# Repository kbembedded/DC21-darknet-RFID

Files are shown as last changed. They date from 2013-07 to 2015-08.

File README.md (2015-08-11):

DC21-darknet-RFID
=================

Note: This project is deprecated in favor of the EM4100_Cloner available here: https://github.com/kbembedded/EM4100_Cloner

Send any quesions to kris@kbembedded.com

Software, schematics, board, etc. for the DEF CON21 darknet ARG in the HHV

This project is based on the RFID_Emulator from http://www.kukata86.com/en/description-and-development-RFID-emulator

The RFID-emulator/ folder contains sources for the pic12f683 microcontroller to act as two types of LF RFID cards.  A standard EM4100, as well as EM4450/EM4150 to be compatible with the RFID reader and RFID reader/writer module from Parallax.  

The RFID-readerwriter/ folder contains spin sources for a Parallax reader/writer module connected to a Propeller, using a 4x4 matrix keypad interface, and an HD44780 LCD screen.

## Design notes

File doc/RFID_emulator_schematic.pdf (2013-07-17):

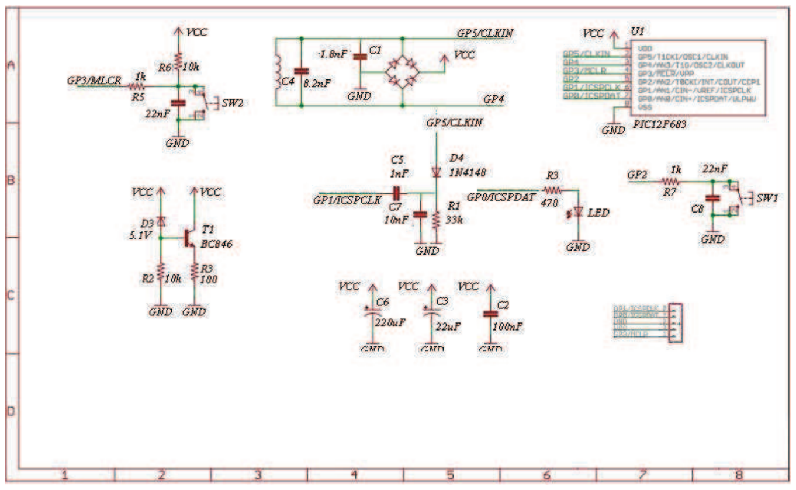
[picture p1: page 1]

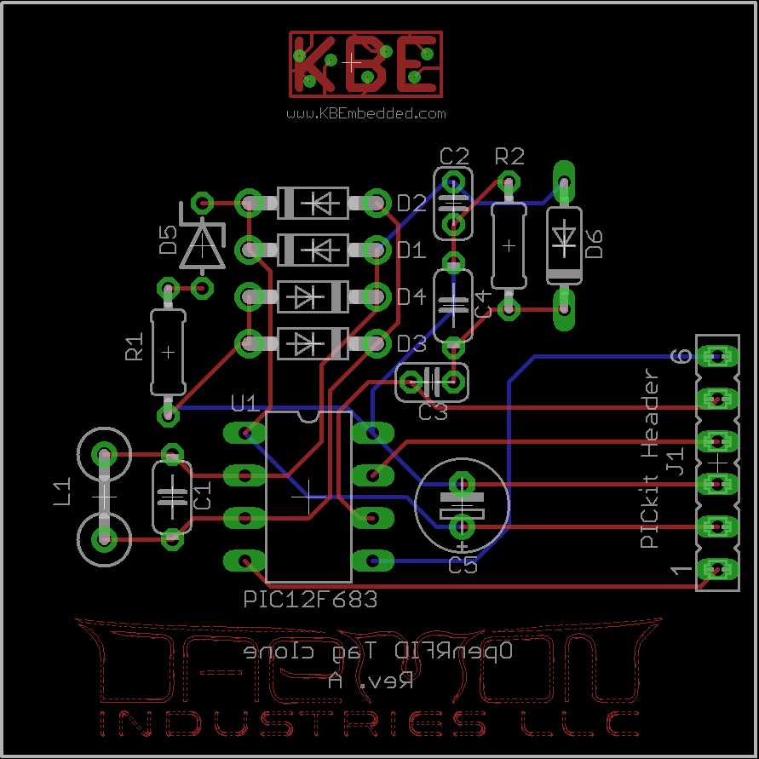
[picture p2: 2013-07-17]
eagle/openrfid.png

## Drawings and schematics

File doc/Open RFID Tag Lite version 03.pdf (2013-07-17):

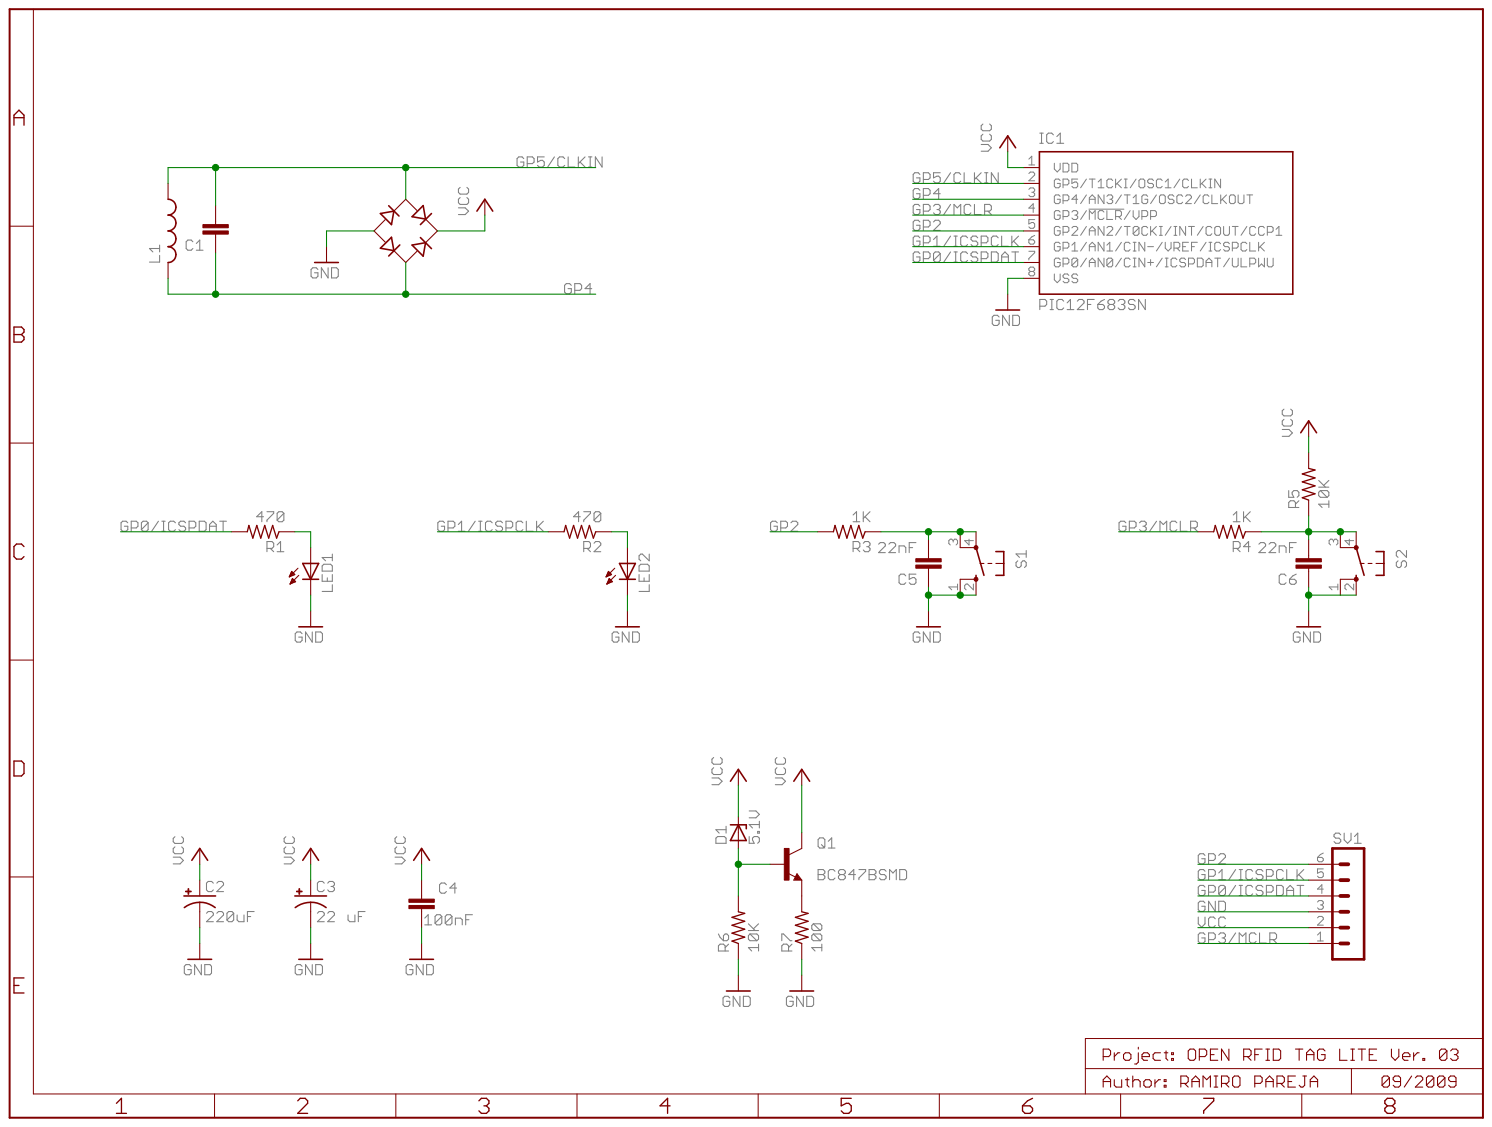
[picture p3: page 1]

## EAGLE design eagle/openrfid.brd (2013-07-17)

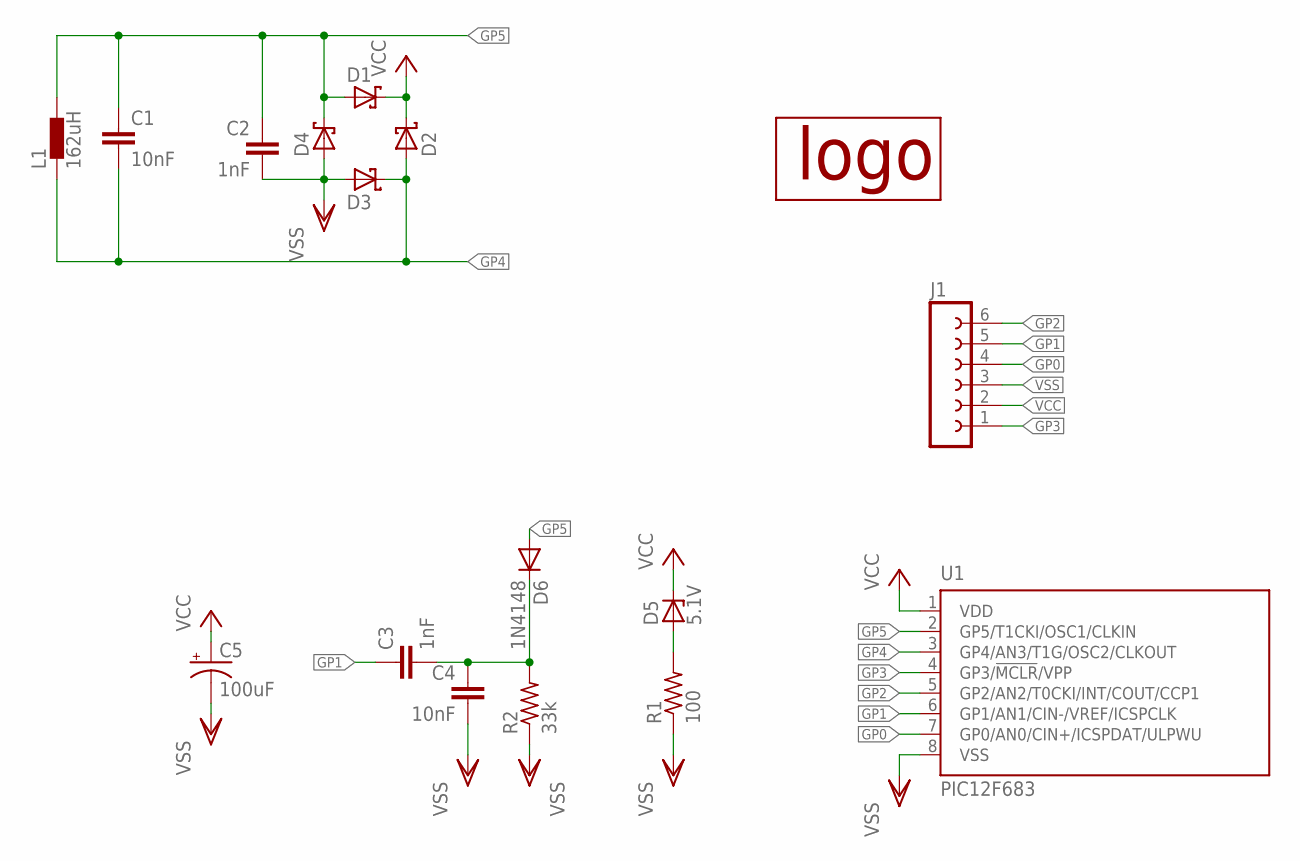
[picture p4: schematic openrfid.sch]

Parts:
C1, C4: 10nF; C050-024X044
C2, C3: 1nF; C025-024X044
C5: 100uF; E2,5-6E
D1, D2, D3, D4: 1N5817-B; DO41-7.6
D5: 5.1V; ZDIO-5
D6: 1N4148; DO35-7
J1: FE06-1; FE06
L1: 162uH; BL02RN2
R1: 100; 0204/7
R2: 33k; 0204/7
U1: PIC12F683; DIL8
U$1: KBELOGO-SILK

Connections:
GP0: J1.4, U1.7 (GP0/AN0/CIN+/ICSPDAT/ULPWU)
GP1: C3.1, J1.5, U1.6 (GP1/AN1/CIN-/VREF/ICSPCLK)
GP2: J1.6, U1.5 (GP2/AN2/T0CKI/INT/COUT/CCP1)
GP3: J1.1, U1.4 (GP3/!MCLR!/VPP)
GP4: C1.2, D2.A, D3.C, L1.1, U1.3 (GP4/AN3/T1G/OSC2/CLKOUT)
GP5: C1.1, C2.1, D1.A, D4.C, D6.A, L1.2, U1.2 (GP5/T1CKI/OSC1/CLKIN)
unnamed: D5.A, R1.2
unnamed: C3.2, C4.1, D6.C, R2.2
VCC: C5.+, D1.C, D2.C, D5.C, J1.2, U1.1 (VDD)
VSS: C2.2, C4.2, C5.-, D3.A, D4.A, J1.3, R1.1, R2.1, U1.8 (VSS)

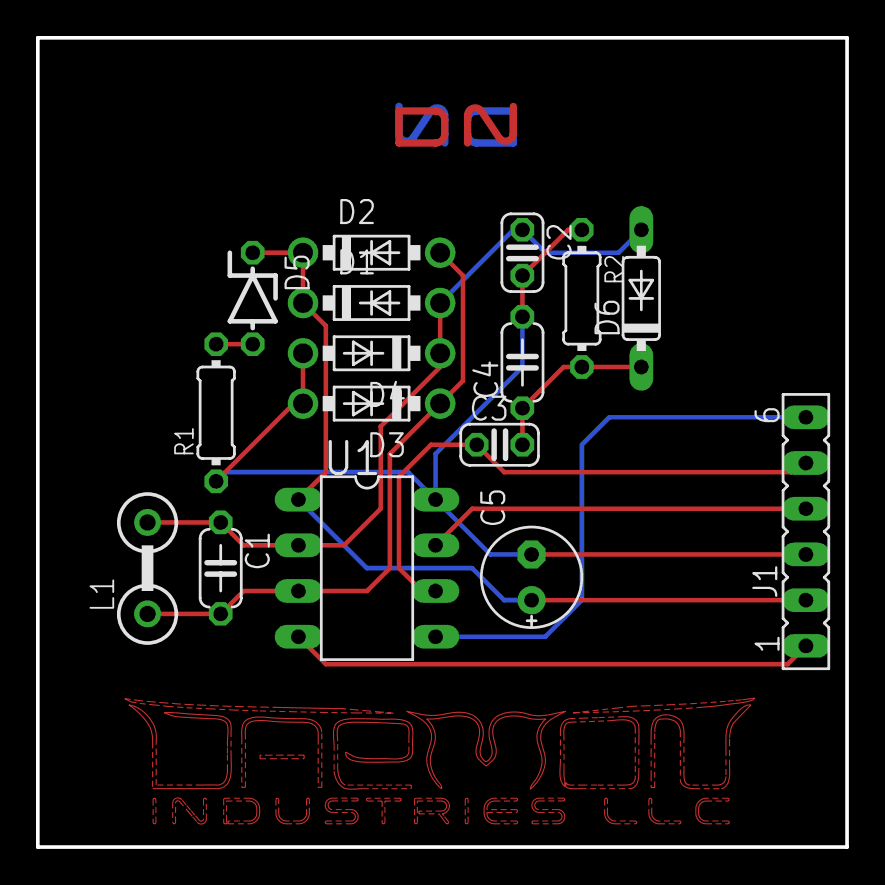
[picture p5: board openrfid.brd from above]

Board: 2 copper layers, 45.0 x 45.0 mm, 17 parts (1 on the bottom side), 10 nets.

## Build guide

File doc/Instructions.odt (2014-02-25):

EM4100 (and beyond) RFID Tag Kit

This kit contains everything needed to build a low frequency EM4100 compatible RFID transponder tag based on a PIC microcontroller. All of the software and documentation can be found on github: https://github.com/kbembedded/DC21-darknet-RFID

Software (as of July 30th 2013) only supports an EM4100 standard; however, it is planned to implement EM4150/EM4450 read/write compatibility. The hardware is already in place to support both of these modes, as well as future fun shenanigans. The PIC12F683 in this kit is pre-programmed and will work out of the box. If there are any issues, please ask for help in the HHV or email support@kbembedded.com

You may notice an interesting theming of the PCB, as this device was intended for use in the DarkNet game running in the HHV over DC21, but, lack of write support basically killed any quest trees for RFID. But, go check out the game anyway. It will be a blast!

Label | Description | If there are any missing parts, talk to someone in the HHV, or email
U1 | PIC12F683 | support@kbembedded.com and indicate the parts that are missing. Please
R1 | 100ohm | also include a mailing address for sending replacement parts.
R2 | 33kOhm | Notes about assembly:
D1, D2, D3, D4 | Schottky Diode | U1, D1, D2, D3, D4, D5, D6, and C5 have a specific orientation
D5 | 5.1V Zener Diode | U1 has a dimple to mark pin 1, line up with the “U1” name on the PCB
D6 | 1N4148 Signal Diode | D1-D6 match up stripe on the diode with stripe on the PCB
C1, C4 | 10nF Ceramic Capacitor | C5 has a white stripe on the side, this is negative (cathode)
C2, C3 | 1nF Ceramic Capacitor | The stripe must be opposite the “+” symbol on the PCB!
C5 | 100uF Electrolytic Capacitor | D5 and D6 look very similar, take careful note of their differences
J1 | 6-pin Header (optional) | D5 will have “5V1” stamped on the side of it
L1 | 162uH Inductor/antenna | L1 is optional and is a PICkit2/3 programming header, not needed for basic function

Building L1:

In the kit is ~5m of 40ga wire wrapped around a thread bobbin; the start of the wire is wrapped around a hole and left hanging free. Part of the assembly fun is rolling your own antenna coil that needs to be tuned to 125kHz. The bobbin CANNOT be used as a core to wrap the antenna around, as it is too small. In order to ensure the highest energy transfer with most RFID readers, the loop radius should to be between 17.5mm and 30mm.

LC resonant frequency in Hz = (1/(2*π*sqrt(L*C))) Plugging in 162uH and 10nF gives a frequency of 125,107Hz. While this is not exact, it is close enough for us, since transponders and transceivers operate within 100kHz-150kHz

Now the fun part, calculating circular loop inductance:

Where:

Lcircle is the desired inductance in Henrys

N is number of turns

R is radius of circle in meters

a is radius of wire in meters (40ga is .00003937m)

µr is relative permeability of the wire material (copper wire is 0.999994)

µ0 is permeability of free space, constant of 4π×10^−7

Get as close to 162uH as possible. Note that it is not required to use the 40ga wire included, you can get creative! The backside of this paper intentionally left blank to be used for calculations. :)

If you just want to get this damn thing built, search the internet for “Circular loop inductance calculators” or go bug someone in the HHV to help.

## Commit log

2013-07-17 Initial commit of sources, eagle cad, and docs for tag Initial commit of sources for custom reader/writer rig
    [openrfid.brd, openrfid.sch]
2013-07-20 Add R/W Demo Code for bs2
    BS2 demo code for Parallax RFID reader-writer is added in
    ~\RFID-readerwriter\bs2\. Original source for propeller moved to
    ~\RFID-readerwriter\prop\.
2013-07-20 Update BS2 Demo Code
    Pin choices and stamp header updated to match kris's awesome breadboard
    layout.
2013-07-24 Add RFID Printer code for Read Module
    Adds code for the reader module to print out the received RFID tag data.
    Also found the location of the RFID memory in the emulator code, added
    comments to it.
    Only strange thing is that the emulator is no longer readable if I
    change any of the data...
2013-07-25 Add User Manual
    Started on user manual for the event. Contains a bill of materials.
2013-07-30 Added/updated comments Force us in to not clone mode, since we dont have a button Changed EE_RFID_MEMORY default value Commented out all macros and definitions using button1, this PCB has no button P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
2013-07-30 Moved instructions to doc folder Added kit stickers to be printed on 3.9x6 paper
2013-07-31 Grammatical fixes Cleared up some info wiht the antenna design
